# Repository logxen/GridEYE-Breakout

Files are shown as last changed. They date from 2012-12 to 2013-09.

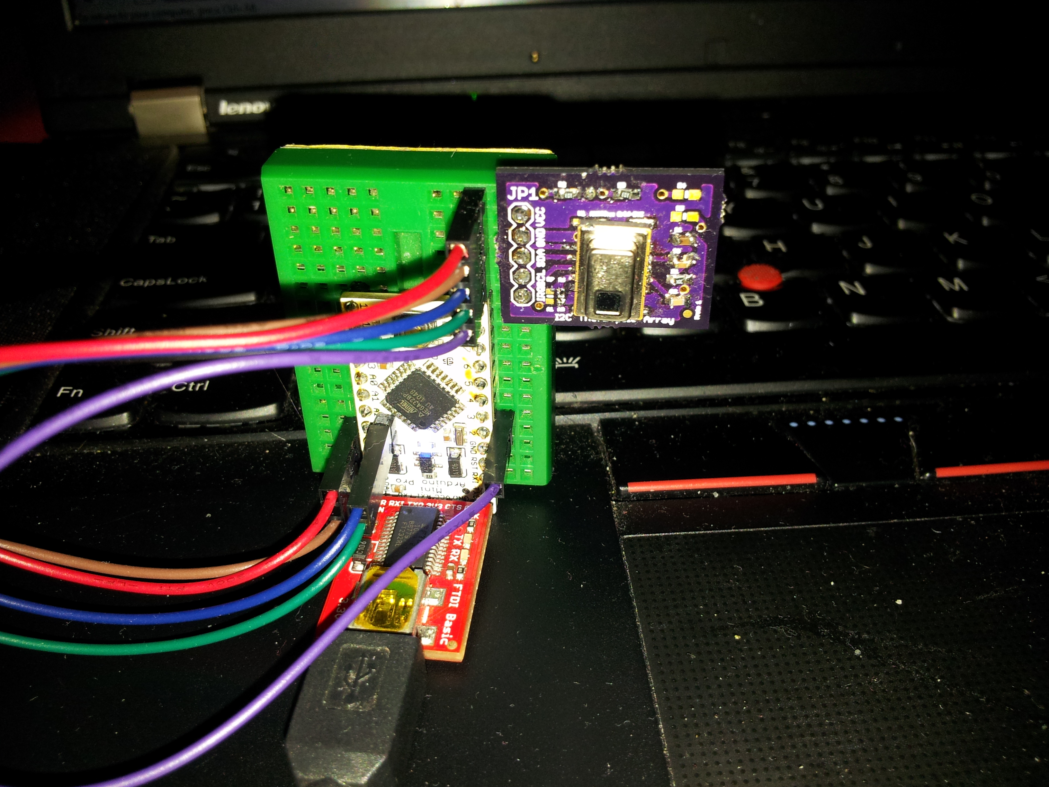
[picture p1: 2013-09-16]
board/prototype.jpg

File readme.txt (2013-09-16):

OVERVIEW

This is a breakout board for the Panasonic Grid-EYE AMG88xx line of thermopile arrays. The sensors are available in both 3.3v and 5v flavors and capture 8 by 8 pixels of far ir data.

The demo firmware is an Arduino sketch and runs on an arduino. (http://arduino.cc/) It probably requires at v1.0 ide. Check out Arduino docs for how to wire an i2c device.

The demo software is a Processing sketch. (http://processing.org/) Processing is what the Arduino ide is based on and I feel that they make a nice set. It expects to connect to the arduino via a serial port. You will need to manually set the serial port in the source file.

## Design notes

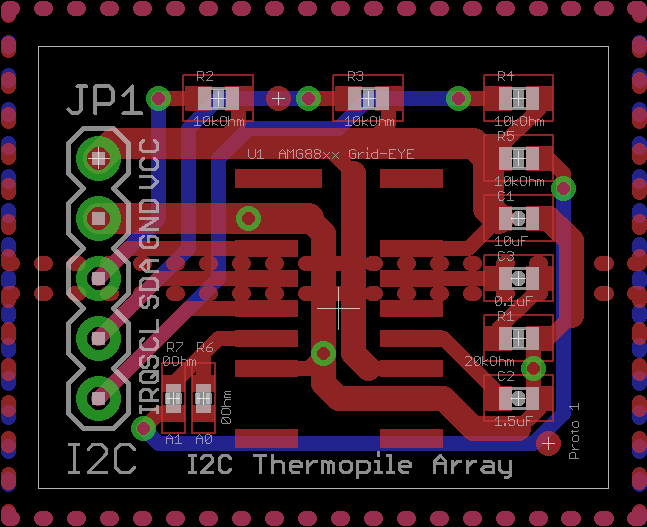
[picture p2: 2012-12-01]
board/GridEYE-Breakout.png

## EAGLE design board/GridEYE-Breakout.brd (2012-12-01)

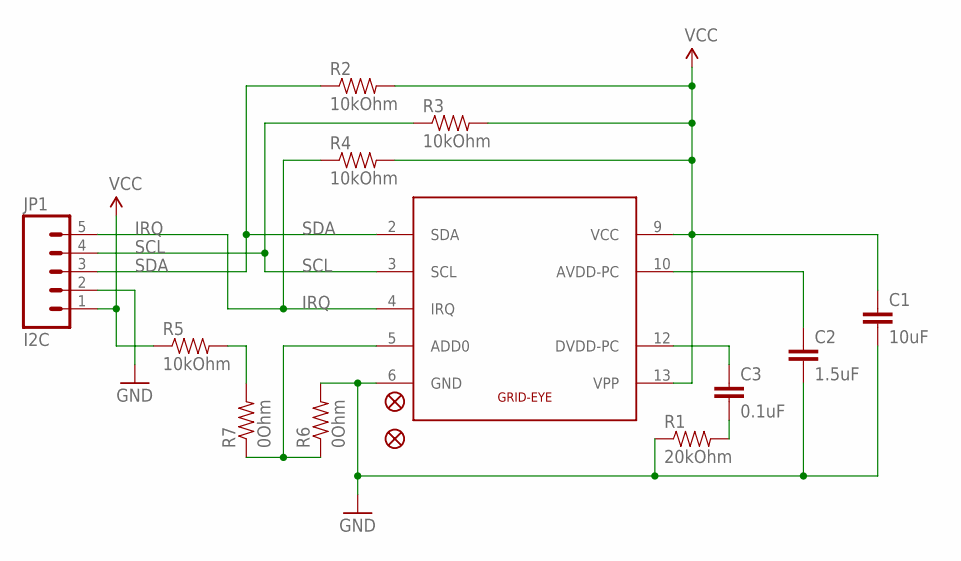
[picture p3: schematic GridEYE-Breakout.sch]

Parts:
C1: 10uF; 0603-CAP
C2: 1.5uF; 0603-CAP
C3: 0.1uF; 0603-CAP
JP1: I2C; 1X05
JP2, JP3: FIDUCIAL1X2; FIDUCIAL-1X2
R1: 20kOhm; 0603-RES
R2, R3, R4, R5: 10kOhm; 0603-RES
R6, R7: 0Ohm; 0402-RES
U1: GRID-EYE

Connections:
ADD0: R6.1, R7.1, U1.5 (ADD0)
AVDD: C2.1, U1.10 (AVDD-PC)
DVDD: C3.1, U1.12 (DVDD-PC)
GND: C1.2, C2.2, JP1.2, R1.1, R6.2, U1.6 (GND)
IRQ: JP1.5, R4.1, U1.4 (IRQ)
unnamed: R5.2, R7.2
unnamed: C3.2, R1.2
SCL: JP1.4, R3.1, U1.3 (SCL)
SDA: JP1.3, R2.1, U1.2 (SDA)
VCC: C1.1, JP1.1, R2.2, R3.2, R4.2, R5.1, U1.9 (VCC), U1.13 (VPP)

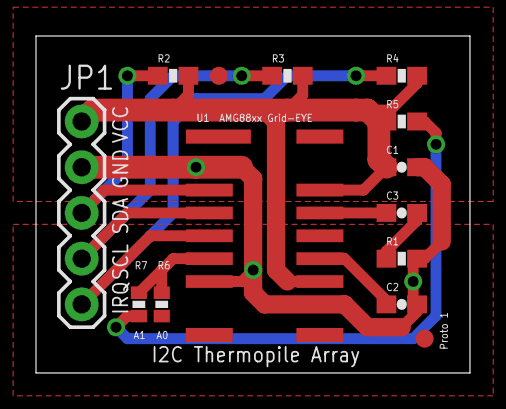
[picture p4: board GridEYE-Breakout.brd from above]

Board: 2 copper layers, 24.1 x 18.7 mm, 14 parts (0 on the bottom side), 10 nets.

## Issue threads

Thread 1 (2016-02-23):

PCB is flawed

Bort-Plate, 2016-02-23:
The PCB traces and cap values do not match the datasheet for the Grideye.

The Data sheet has Pin 10 (AVDD-PC) going to a 1uF cap, then a 20Ω resistor, then ground. And Pin 12 goes to a 1.5uF cap then ground.

But, the "proto1" PCB from this git has pins 10 and 12 swapped, with pin 12 getting the resistor, AND the cap value is wrong (0.1uF instead of 1uF)!

This also means that the PCB layout that currently exists on oshpark.com is also wrong!

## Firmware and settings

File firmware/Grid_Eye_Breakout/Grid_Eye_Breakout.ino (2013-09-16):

#include <Wire.h>

byte pixelTempL;
byte pixelTempH;
char addr = 0x68;
float celsius;
float aveTemp;

int irqPin = 2;
int pwmPin = 3;

void setup() {
  Wire.begin();
  Serial.begin(115200);
  
  pinMode(irqPin, INPUT);
  pinMode(pwmPin, OUTPUT);

//  analogWrite(pwmPin, 255);
}

void loop() {
  Serial.print("Grid-EYE:\r\n");
  
  pixelTempL = 0x80;
  aveTemp = 0;
  
  for(int pixel = 0; pixel < 64; pixel++){
    Wire.beginTransmission(addr);
    Wire.write(pixelTempL);
    Wire.endTransmission();
    Wire.requestFrom(addr, 2);
    byte lowerLevel = Wire.read();
    byte upperLevel = Wire.read();

/*    
    Wire.beginTransmission(addr);
    Wire.write(pixelTempH);
    Wire.endTransmission();
    Wire.requestFrom(addr, 1);
    byte upperLevel = Wire.read();
*/

    int temperature = ((upperLevel << 8) | lowerLevel);
//    int temperature = temp - 2048;
    if (temperature > 2047){
      temperature = temperature - 4096;
//      temperature = -(2048 - temperature);
    }
    
    celsius = temperature * 0.25;
    
    Serial.print(celsius);
    Serial.print(" ");
    if((pixel+1)%8 == 0){
      Serial.print("\r\n");
    }
    
    switch(pixel){
    case 27:
    case 28:
    case 35:
    case 36:
      aveTemp += celsius;
      break;
    default:
      break;
    }
    
    pixelTempL = pixelTempL + 2;
  }
  
  Wire.beginTransmission(addr);
  Wire.write(0x0E);
  Wire.endTransmission();
  Wire.requestFrom(addr, 2);
  byte upperLevelTherm = Wire.read();
  byte lowerLevelTherm = Wire.read();
  
/*
  Wire.beginTransmission(addr);
  Wire.write(0x0F);
  Wire.endTransmission();
  Wire.requestFrom(addr, 1);
  byte lowerLevelTherm = Wire.read();
*/

  int temperatureTherm = ((lowerLevelTherm << 8) | upperLevelTherm);
  
  float celsiusTherm = temperatureTherm * 0.0625;
  
  Serial.print(celsiusTherm);
  Serial.print("\r\n\r\n");
  
  aveTemp *= 0.25;
  
  
  delay(25);
}

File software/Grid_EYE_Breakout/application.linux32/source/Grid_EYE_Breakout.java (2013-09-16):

import processing.core.*; 
import processing.data.*; 
import processing.event.*; 
import processing.opengl.*; 

import processing.serial.*; 

import java.util.HashMap; 
import java.util.ArrayList; 
import java.io.BufferedReader; 
import java.io.PrintWriter; 
import java.io.InputStream; 
import java.io.OutputStream; 
import java.io.IOException; 

public class Grid_EYE_Breakout extends PApplet {



Serial uart;
int theKey;
String theBuf;
int theSize = 8;
int theScale = 64;
float[][] theBitmap = new float[8][8];
float theTemp = 27.0f;

int state = 0;

public void setup(){
  size(theSize*theScale,theSize*theScale);
//  PFont font = createFont(PFont.list()[2],14);
//  textFont(font);
  textSize(24);
  
  String uartName = Serial.list()[0];
  uart = new Serial(this, uartName, 115200);
  uart.bufferUntil('\n');
}

public void draw(){
  background(0);
  for(int i=0; i<theSize; i++){
    for(int j=0; j<theSize; j++){
      float temp = theBitmap[i][j];
      float r = 0;
      float b = 0;
      float g = 0;
      if(temp > theTemp){
        r = sqrt(temp - theTemp) * 24;
      } else if(temp < theTemp){
        b = sqrt(theTemp - temp) * 24;
      }
      stroke(r,g,b);
      fill(r,g,b);
      rect(i*theScale,j*theScale,theScale,theScale);
      stroke(255);
      fill(255);
      
      // uncomment this line for celcius display
      text(PApplet.parseInt(temp), (i+0.1f)*theScale,(j+0.5f)*theScale);
      // uncomment this line for farenheit display
//      text(int(1.8*temp+32), (i+0.1)*theScale,(j+0.85)*theScale);
    }
  }
}

public void serialEvent(Serial port){
  theBuf = trim(port.readString());
//  println(theBuf);
  if(theBuf.length() == 9){
    if(theBuf.equals("Grid-EYE:")) state = 1;
  } else if(state > 0 && state <= 8){
    float[] pix = PApplet.parseFloat(split(theBuf, ' '));
    for(int i=0; i<theSize; i++){
      theBitmap[i][state-1] = pix[i];
//      theBitmap[i][state-1] = (pix[i]-20)*16;
    }
    state++;
  } else if(state == 9){
    // get ambient temp
//    theTemp = float(theBuf);
    // println(pix[i]);
    state = 0;
  }
}

public void keyPressed(){
  uart.write(key);
  theKey = key;
}

  static public void main(String[] passedArgs) {
    String[] appletArgs = new String[] { "Grid_EYE_Breakout" };
    if (passedArgs != null) {
      PApplet.main(concat(appletArgs, passedArgs));
    } else {
      PApplet.main(appletArgs);
    }
  }
}

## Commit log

2012-12-01 Initial commit of prototype 1
    [GridEYE-Breakout.brd, GridEYE-Breakout.sch]
2013-09-16 Added demo firmware and software
    [GridEYE-Breakout.brd, GridEYE-Breakout.sch]

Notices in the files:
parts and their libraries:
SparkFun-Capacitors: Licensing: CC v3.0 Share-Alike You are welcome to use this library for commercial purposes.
